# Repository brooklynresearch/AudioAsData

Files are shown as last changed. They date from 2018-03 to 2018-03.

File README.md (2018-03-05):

Vibrotextiles
=============
This repo is for all hardware and firmware associated with the vibrotextiles.
This is still a work in progress and will be updated as future commits occur.

Firmware
--------
This folder contains all the firmware, libraries, and testing instructions for the vibrotextiles

Javascript
----------
This folder contains a simple web based tester for APSK.

Hardware
--------
This folder contains all the schematics, layouts, components, production files, and artwork needed for the vibrotextiles.

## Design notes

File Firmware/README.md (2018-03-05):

Vibrotextiles - Firmware
========================
This Folder is for all the firmware and test processes associated with the vibrotextiles

Arduino
--------
This folder contains all the initial arduino code and possible libraries for the [NRF53832 BLE module](https://www.adafruit.com/product/3406).
Follow this [Adafruit NRF52832 Tutorial](https://learn.adafruit.com/bluefruit-nrf52-feather-learning-guide/introduction) to get started.

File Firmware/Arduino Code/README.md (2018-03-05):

Vibrotextiles - Arduino Code
============================
 To get started uploading code to the NRF52832 module sue the [Adafruit NRF52832 Tutorial](https://learn.adafruit.com/bluefruit-nrf52-feather-learning-guide/introduction).

 openocd
 -------
 Setup for debugging.  

 sketch_ppi_test
 ---------------
 Current working sketch

 sketch_testADC
 --------------
 Testing the ADC on the NRF52832

 test_code
 ---------
 Initial test code

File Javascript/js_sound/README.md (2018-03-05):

Vibrotextiles - js_sound
========================
This folder is for quick testing of the APSK function with the initial tests BKR did for the NRF52832

index
--------
Original javascript app to send data through APSK moduation.  Does not contain any error correction/checksum.

onthefly
----------
This folder contains a simple web based tester for APSK  Each data frame has 5 bytes, 4 of them are data, 1 of them is CRC checksum. At 1200 bps.  The carrier frequency is 1.2kHz to 2.2kHz.

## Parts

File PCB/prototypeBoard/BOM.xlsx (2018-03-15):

Qty | Value | Device | Package | Parts | Description | DIGIKEY | LCSC | PROD_ID | SF_ID | SPICEPREFIX | VALUE | 10 sets count
4 | 100 | RESISTOR0805_NOOUTLINE | 0805-NO | R18, R19, R31, R32 | Resistors |  | C153166 |  |  |  |  | 40
6 | 100k | R-EU_R0805 | R0805 | R5, R8, R9, R11, R12, R17 | RESISTOR, European symbol |  | C103905 |  |  | R |  | 60
4 | 100nF | C-EUC0805 | C0805 | C13, C17, C18, C29 | CAPACITOR, European symbol |  | C28378 |  |  | C |  | 40
4 | 10k | R-EU_R0805 | R0805 | R7, R20, R24, R28 | RESISTOR, European symbol |  | C84376 |  |  | R |  | 40
11 | 10uF | C-EUC0805 | C0805 | C3, C5, C6, C8, C10, C11, C14, C15, C16, C21, C25 | CAPACITOR, European symbol |  | C1713 |  |  | C |  | 110
2 | 10uH | INDUCTOR0805-NO | 0805-NO@1 | L1, L2 | Inductors |  | C112611 |  |  |  |  | 20
1 | 1N4148 | DIODESOD-323 | SOD-323 | D4 | Diode |  | C99332 |  |  |  |  | 10
7 | 1k | R-EU_R0805 | R0805 | R1, R2, R3, R13, R16, R29, R30 | RESISTOR, European symbol |  | C101404 |  |  | R |  | 70
1 | 1nF | C-EUC0805 | C0805 | C12 | CAPACITOR, European symbol |  | C16005 |  |  | C |  | 10
5 | 1uF | C-EUC0805 | C0805 | C4, C19, C20, C24, C26 | CAPACITOR, European symbol |  | C29822 |  |  | C |  | 50
1 | 2.2K | R-EU_R0805 | R0805 | R10 | RESISTOR, European symbol |  | C101970 |  |  | R |  | 10
2 | 20k | R-EU_R0805 | R0805 | R14, R15 | RESISTOR, European symbol |  | C101548 |  |  | R |  | 20
4 | 220pF | CAP_CERAMIC0805-NOOUTLINE | 0805-NO | C22, C23, C35, C36 | Ceramic Capacitors |  | C46326 |  |  |  |  | 40
2 | 22pF | C-EUC0805 | C0805 | C1, C2 | CAPACITOR, European symbol |  | C1836 |  |  | C |  | 20
1 | 2M | R-EU_R0805 | R0805 | R6 | RESISTOR, European symbol |  | C26112 |  |  | R |  | 10
2 | 300pF | C-EUC0805 | C0805 | C7, C9 | CAPACITOR, European symbol |  | C1735 |  |  | C |  | 20
1 | 32.768 | XTAL-3.2X1.5 | XTAL3215 | X4 | Low cost SMT crystals, no capacitors included |  | C48615 |  |  |  |  | 10
1 | 4u20329 | USB_MICRO_20329_V2 | 4UCONN_20329_V2 | X3 | USB Connectors |  | C91146 |  |  |  |  | 10
4 | 5K | R-EU_R0805 | R0805 | R21, R22, R34, R35 | RESISTOR, European symbol |  | C84375 |  |  | R |  | 40
1 | 806K | R-EU_R0805 | R0805 | R4 | RESISTOR, European symbol |  | C104516 |  |  | R |  | 10
2 | AP2112(3.3V) | VREG_SOT23-5 | SOT23-5 | U2, U5 | SOT23-5 Fixed Voltage Regulators |  | C51118 |  |  |  |  | 20
2 | APA1022020 | APA1022020 | APA102_2020 | U$45, U$51 | APA102C 5050 RGB LED | 1568-1826-ND |  |  |  |  |  | 20
1 | BLUE | LED0805_NOOUTLINE | CHIPLED_0805_NOOUTLINE | D2 | LED |  | C2293 |  |  |  |  | 10
1 | DFU | SWITCH_TACT_SMT4.6X2.8 | BTN_KMR2_4.6X2.8 | SW2 | SMT Tact Switches | CKN10246CT-ND |  |  |  |  |  | 10
1 | DMG3415U-7 | MOSFET-P | SOT23-R | Q3 | P-Channel Mosfet |  | C10487 |  |  |  |  | 10
1 | FRST | TESTPOINT1.5X2.0MM_NOCREAM | PAD-1.5X2.0 | TP2 | Test Point |  |  |  |  |  |  | 10
4 | Ferrite | FERRITE_0805 | _0805 | FB1, FB2, FB5, FB6 | Ferrite Bead |  | C12389 |  |  |  |  | 40
1 | JSTPH | CON_JST_PH_2PIN | JSTPH2 | X2 | JST 2-Pin Right-Angle Connector | 455-1749-1-ND |  |  |  |  |  | 10
1 | LMV324 | LMV324 | SO14 | U4 | IC LMV324 Quad Op Amp |  | C7974 | IC-08227 |  |  | LMV324 | 10
1 | MBR120 | DIODE-SCHOTTKYSOD-123 | SOD-123 | D5 |  |  | C130880 |  |  |  |  | 10
1 | MCP73831T-2ACI/OT | MCP73831/2 | SOT23-5 | U3 | MCP73831/2 LIPO Charger |  | C14879 |  |  |  |  | 10
1 | MDBT42 | NRF52832_MODULE_MDBT42 | BLE_MODULE_RAYTAC_MDBT42 | U1 | MDBT42 - BLE Module (nRF52832 QFN) | 1597-1434-ND |  |  |  |  |  | 10
1 | ORANGE | LED0805_NOOUTLINE | CHIPLED_0805_NOOUTLINE | CHG | LED |  | C154481 |  |  |  |  | 10
2 | PAM8302AASCR | AUDIOAMP_PAM8302A | MSOP8_0.65MM | U6, U8 | PAM8302A - 2.5W Class-D Mono Audio Amplifier |  | C113367 |  |  |  |  | 20
1 | RED | LED0805_NOOUTLINE | CHIPLED_0805_NOOUTLINE | D1 | LED |  | C72037 |  |  |  |  | 10
1 | RST | SWITCH_TACT_SMT4.6X2.8 | BTN_KMR2_4.6X2.8 | SW1 | SMT Tact Switches | CKN10246CT-ND |  |  |  |  |  | 10
1 | SWITCH_SPDT | SWITCH_SPDT | KPS-1290 | SW3 | SWCH-10651 |  | C128955 | SWCH-10651 |  |  |  | 10
2 | TBD | CAP_CERAMIC0805-NOOUTLINE | 0805-NO | C30, C37 | Ceramic Capacitors |  |  |  |  |  |  | 20

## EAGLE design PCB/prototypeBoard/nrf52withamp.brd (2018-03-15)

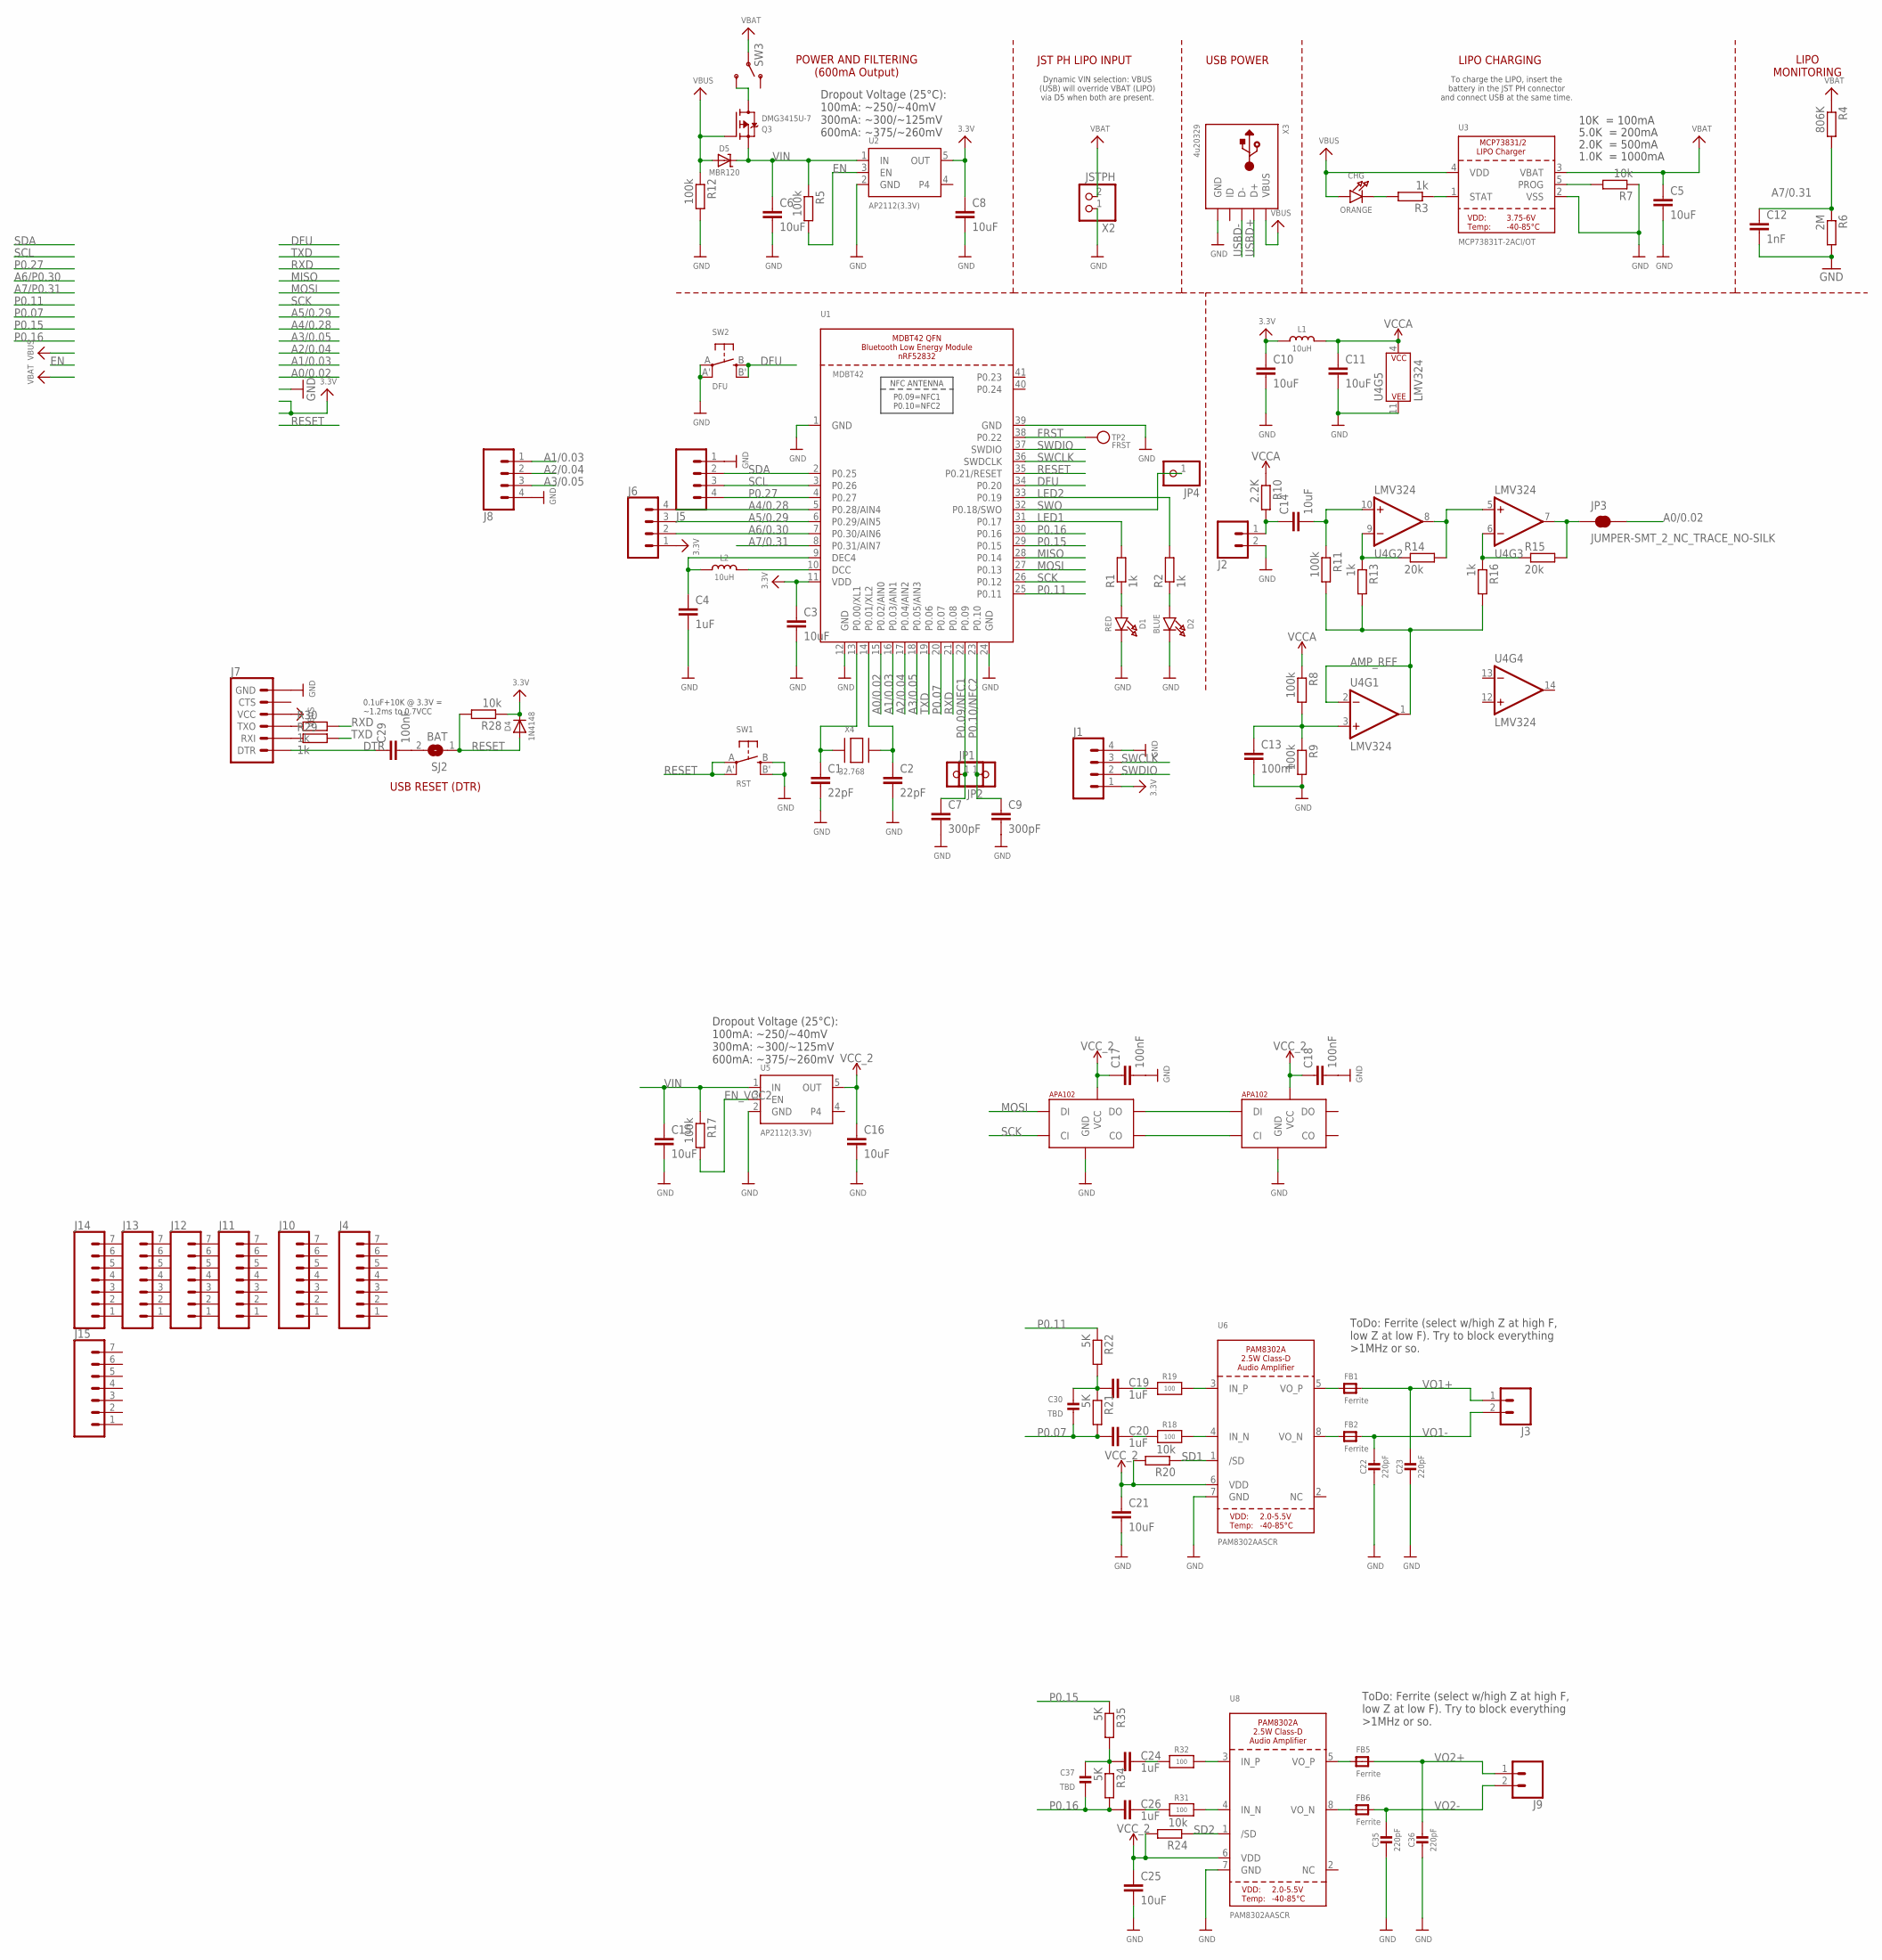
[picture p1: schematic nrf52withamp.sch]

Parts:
C1, C2: 22pF; C0805; LCSC C1836
C3, C5, C6, C8, C10, C11, C14, C15, C16, C21, C25: 10uF; C0805; LCSC C1713
C4, C19, C20, C24, C26: 1uF; C0805; LCSC C29822
C7, C9: 300pF; C0805; LCSC C1735
C12: 1nF; C0805; LCSC C16005
C13, C17, C18, C29: 100nF; C0805; LCSC C28378
C22, C23, C35, C36: 220pF; 0805-NO; LCSC C46326
C30, C37: TBD; 0805-NO
CHG: ORANGE; CHIPLED_0805_NOOUTLINE; LCSC C154481
D1: RED; CHIPLED_0805_NOOUTLINE; LCSC C72037
D2: BLUE; CHIPLED_0805_NOOUTLINE; LCSC C2293
D4: 1N4148; SOD-323; LCSC C99332
D5: MBR120; SOD-123; LCSC C130880
FB1, FB2, FB5, FB6: Ferrite; _0805; LCSC C12389
J1: CONN_04SMD; 1X04_SMD_RA_MALE
J2, J3, J9: CONN_02; 1X02
J4, J10, J11, J12, J13, J14, J15: CONN_07; 1X07
J5, J6, J8: CONN_041.27MM; 1X04_1.27MM
J7: 6_PIN_SERIAL_TARGETRA_SMT; 6_PIN_SERIAL_TARGET_SIDE_RA_SMT
JP1, JP2, JP4: HEADER-1X12MM; 1X01_2MM
JP3: JUMPER-SMT_2_NC_TRACE_NO-SILK; SMT-JUMPER_2_NC_TRACE_NO-SILK
L1, L2: 10uH; 0805-NO@1; LCSC C112611
Q3: DMG3415U-7; SOT23-R; LCSC C10487
R1, R2, R3, R13, R16, R29, R30: 1k; R0805; LCSC C101404
R4: 806K; R0805; LCSC C104516
R5, R8, R9, R11, R12, R17: 100k; R0805; LCSC C103905
R6: 2M; R0805; LCSC C26112
R7, R20, R24, R28: 10k; R0805; LCSC C84376
R10: 2.2K; R0805; LCSC C101970
R14, R15: 20k; R0805; LCSC C101548
R18, R19, R31, R32: 100; 0805-NO; LCSC C153166
R21, R22, R34, R35: 5K; R0805; LCSC C84375
SJ2: BAT; SOLDERJUMPER_CLOSEDWIRE
SW1: RST; BTN_KMR2_4.6X2.8; DIGIKEY CKN10246CT-ND
SW2: DFU; BTN_KMR2_4.6X2.8; DIGIKEY CKN10246CT-ND
SW3: SWITCH_SPDT; KPS-1290; LCSC C128955
TP2: FRST; PAD-1.5X2.0
U1: MDBT42; BLE_MODULE_RAYTAC_MDBT42; DIGIKEY 1597-1434-ND
U2, U5: AP2112(3.3V); SOT23-5; LCSC C51118
U3: MCP73831T-2ACI/OT; SOT23-5; LCSC C14879
U4: LMV324; SO14; LCSC C7974
U6, U8: PAM8302AASCR; MSOP8_0.65MM; LCSC C113367
U$45, U$51: APA1022020; APA102_2020; DIGIKEY 1568-1826-ND
X2: JSTPH; JSTPH2; DIGIKEY 455-1749-1-ND
X3: 4u20329; 4UCONN_20329_V2; LCSC C91146
X4: 32.768; XTAL3215; LCSC C48615

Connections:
3.3V: C3.1, C8.1, C10.1, D4.C, J1.1, J6.1, L1.1, R28.1, U1.11 (VDD), U2.5 (OUT)
A0/0.02: JP3.2, U1.15 (P0.02/AIN0)
A1/0.03: J8.1, U1.16 (P0.03/AIN1)
A2/0.04: J8.2, U1.17 (P0.04/AIN2)
A3/0.05: J8.3, U1.18 (P0.05/AIN3)
A4/0.28: J6.4, U1.5 (P0.28/AIN4)
A5/0.29: J6.3, U1.6 (P0.29/AIN5)
A6/0.30: J6.2, U1.7 (P0.30/AIN6)
A7/0.31: C12.1, R4.2, R6.1, U1.8 (P0.31/AIN7)
AMP_REF: R11.2, R13.2, R16.2, U4.1 (OUT), U4.2 (-IN)
CO1: U$45.CL_OUT (CO), U$51.C_IN (CI)
DFU: SW2.B (S), SW2.B' (S1), U1.34 (P0.20)
DTR: C29.1, J7.1 (DTR)
EN: R5.2, U2.3 (EN)
EN_VCC2: R17.2, U5.3 (EN)
FRST: TP2.P$1, U1.38 (P0.22)
GND: C1.2, C2.2, C3.2, C4.2, C5.2, C6.2, C7.2, C8.2, C9.2, C10.2, C11.2, C12.2, C13.2, C15.2, C16.2, C17.2, C18.2, C21.2, C22.2, C23.2, C25.2, C35.2, C36.2, D1.C, D2.C, J1.4, J2.2, J5.1, J7.6 (GND), J8.4, R6.2, R7.1, R9.2, R12.2, SW1.B (S), SW1.B' (S1), SW2.A, SW2.A' (P1), U1.1 (GND), U1.12 (GND), U1.24 (GND), U1.39 (GND), U2.2 (GND), U3.2 (VSS), U4.11 (P$V-), U5.2 (GND), U6.7 (GND), U8.7 (GND), U$45.GND, U$51.GND, X2.1, X3.BASE@1 (GND), X3.BASE@2 (GND), X3.GND, X3.SPRT@1 (GND), X3.SPRT@2 (GND), X3.SPRT@3 (GND), X3.SPRT@4 (GND)
LED1: R1.2, U1.31 (P0.17)
LED2: R2.2, U1.33 (P0.19)
MISO: U1.28 (P0.14)
MOSI: U1.27 (P0.13), U$45.D_IN (DI)
unnamed: C1.1, U1.13 (P0.00/XL1), X4.P$1
unnamed: C2.1, U1.14 (P0.01/XL2), X4.P$2
unnamed: L2.2, U1.10 (DCC)
unnamed: CHG.C, R3.2
unnamed: D1.A, R1.1
unnamed: C13.1, R8.2, R9.1, U4.3 (+IN)
unnamed: D2.A, R2.1
unnamed: C4.1, L2.1, U1.9 (DEC4)
unnamed: R3.1, U3.1 (STAT)
unnamed: R7.2, U3.5 (PROG)
unnamed: C14.1, J2.1, R10.2
unnamed: C14.2, R11.1, U4.10 (+IN)
unnamed: C29.2, SJ2.2
unnamed: U$45.D_OUT (DO), U$51.D_IN (DI)
unnamed: R13.1, R14.1, U4.9 (-IN)
unnamed: R14.2, U4.5 (+IN), U4.8 (OUT)
unnamed: R15.1, R16.1, U4.6 (-IN)
unnamed: JP3.1, R15.2, U4.7 (OUT)
unnamed: R18.2, U6.4 (IN_N)
unnamed: R19.2, U6.3 (IN_P)
unnamed: C20.2, R18.1
unnamed: FB2.1, U6.8 (VO_N)
unnamed: FB1.1, U6.5 (VO_P)
unnamed: C19.2, R19.1
unnamed: C19.1, C30.1, R21.1, R22.2
unnamed: Q3.3 (D), SW3.S
unnamed: J7.3 (RXI), R29.1
unnamed: J7.2 (TXO), R30.1
unnamed: R31.2, U8.4 (IN_N)
unnamed: R32.2, U8.3 (IN_P)
unnamed: C26.2, R31.1
unnamed: FB6.1, U8.8 (VO_N)
unnamed: FB5.1, U8.5 (VO_P)
unnamed: C24.2, R32.1
unnamed: C24.1, C37.1, R34.1, R35.2
P0.07: C20.1, C30.2, R21.2, U1.20 (P0.07)
P0.09/NFC1: C7.1, JP2.1, U1.22 (P0.09)
P0.10/NFC2: C9.1, JP1.1, U1.23 (P0.10)
P0.11: R22.1, U1.25 (P0.11)
P0.15: R35.1, U1.29 (P0.15)
P0.16: C26.1, C37.2, R34.2, U1.30 (P0.16)
P0.27: J5.4, U1.4 (P0.27)
RESET: D4.A, R28.2, SJ2.1, SW1.A, SW1.A' (P1), U1.35 (P0.21/RESET)
RXD: R30.2, U1.21 (P0.08)
SCK: U1.26 (P0.12), U$45.C_IN (CI)
SCL: J5.3, U1.3 (P0.26)
SD1: R20.1, U6.1 (/SD)
SD2: R24.1, U8.1 (/SD)
SDA: J5.2, U1.2 (P0.25)
SWCLK: J1.3, U1.36 (SWDCLK)
SWDIO: J1.2, U1.37 (SWDIO)
SWO: JP4.1, U1.32 (P0.18/SWO)
TXD: R29.2, U1.19 (P0.06)
USBD+: X3.D+
USBD-: X3.D-
VBAT: C5.1, R4.1, SW3.P, U3.3 (VBAT), X2.2
VBUS: CHG.A, D5.A, J7.4 (VCC), Q3.1 (G), R12.1, U3.4 (VDD), X3.VBUS
VCCA: C11.1, L1.2, R8.1, R10.1, U4.4 (P$V+)
VCC_2: C16.1, C17.1, C18.1, C21.1, C25.1, R20.2, R24.2, U5.5 (OUT), U6.6 (VDD), U8.6 (VDD), U$45.V_CC (VCC), U$51.V_CC (VCC)
VIN: C6.1, C15.1, D5.C, Q3.2 (S), R5.1, R17.1, U2.1 (IN), U5.1 (IN)
VO1+: C23.1, FB1.2, J3.1
VO1-: C22.1, FB2.2, J3.2
VO2+: C36.1, FB5.2, J9.1
VO2-: C35.1, FB6.2, J9.2

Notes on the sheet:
10K = 100mA
5.0K = 200mA
2.0K = 500mA
1.0K = 1000mA
LIPO CHARGING
LIPO MONITORING
To charge the LIPO, insert the battery in the JST PH connector and connect USB at the same time.
POWER AND FILTERING (600mA Output)
JST PH LIPO INPUT
Dynamic VIN selection: VBUS (USB) will override VBAT (LIPO) via D5 when both are present.
Dropout Voltage (25°C): 100mA: ~250/~40mV 300mA: ~300/~125mV 600mA: ~375/~260mV
USB POWER
ToDo: Ferrite (select w/high Z at high F, low Z at low F). Try to block everything >1MHz or so.
USB RESET (DTR)
0.1uF+10K @ 3.3V = ~1.2ms to 0.7VCC

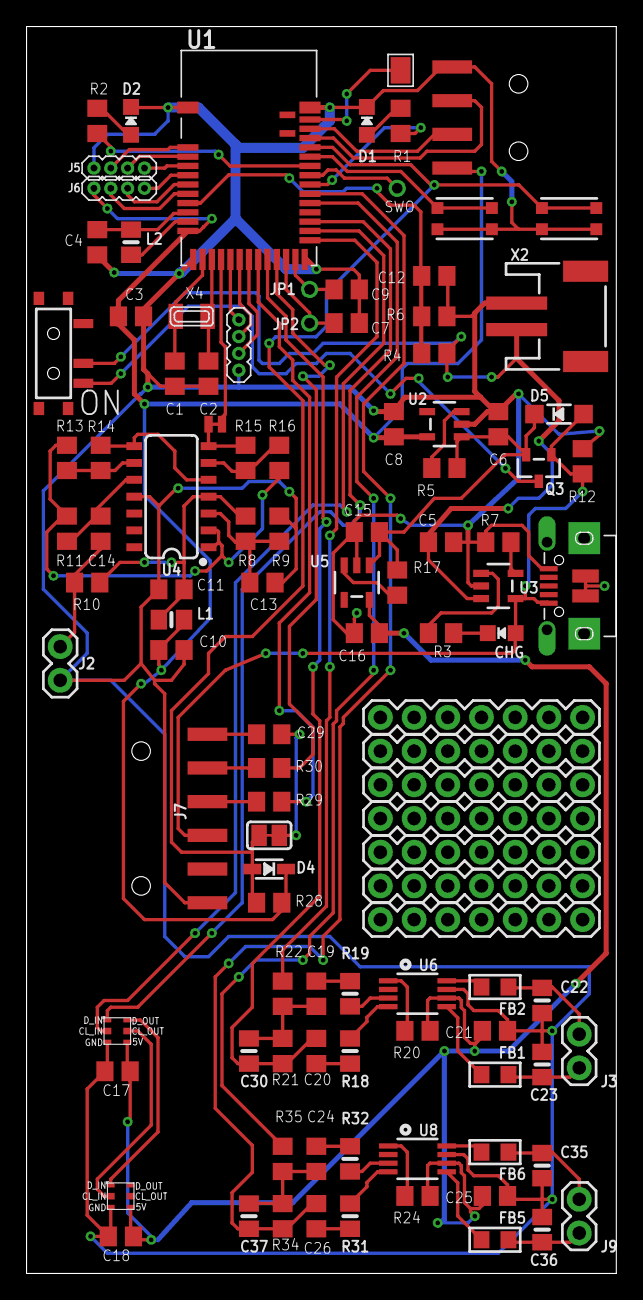
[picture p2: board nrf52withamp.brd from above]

Board: 2 copper layers, 44.5 x 94.0 mm, 109 parts (0 on the bottom side), 82 nets.

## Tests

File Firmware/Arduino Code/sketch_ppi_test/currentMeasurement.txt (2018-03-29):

Measured on Mar 29 2018. With nrf52withamp.brd, Lofelt actuator, OTOjOY induction loop sensor.

Current measured on VBus with Fluke 15B 

LED off, Motor off: 19.25 mA
1 LED Full brightness, Motor off: 34.65mA
2 LED Full brightness, Motor off: 55.2mA
LED off, Motor full vibration @ 100hz: 317 mA
LED off, Motor full vibration @ 10hz: 351 mA
2 LED Full brightness, Motor full vibration @ 100hz: 351mA
2 LED Full brightness, Motor full vibration @ 10hz: 388mA

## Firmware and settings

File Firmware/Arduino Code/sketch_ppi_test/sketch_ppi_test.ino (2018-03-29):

//tested with Univox AutoLoop 2.0 Home Hearing Loop System, modulated with bell202

#define SIGNAL_LEVEL_PIN A6
#define DEBUG_PIN1 A5
#define DEBUG_PIN2 A4
#define NRF52_BLUE_LED 19

#define BUZZER1_PIN1 11
#define BUZZER1_PIN2 7

#define BUZZER2_PIN1 15
#define BUZZER2_PIN2 16

#include <SPI.h>

extern "C"  //https://forums.adafruit.com/viewtopic.php?f=24&t=125410
{
  void TIMER1_IRQHandler();
  void SAADC_IRQHandler();
}

volatile int16_t adcbuffer; //interrupt one each time. other wise auto restart has aline issue

volatile int16_t historyBuffer[8];

volatile bool newData = false;

bool recent3bits[3];

int recent3Bytes[3];

bool outputBit;

int capturePhase = 0;
int processingValue;

unsigned char CRCtable[256] = {0x00, 0x07, 0x0e, 0x09, 0x1c, 0x1b, 0x12, 0x15, 0x38, 0x3f, 0x36, 0x31, 0x24, 0x23, 0x2a, 0x2d, 0x70, 0x77, 0x7e, 0x79, 0x6c, 0x6b, 0x62, 0x65, 0x48, 0x4f, 0x46, 0x41, 0x54, 0x53, 0x5a, 0x5d, 0xe0, 0xe7, 0xee, 0xe9, 0xfc, 0xfb, 0xf2, 0xf5, 0xd8, 0xdf, 0xd6, 0xd1, 0xc4, 0xc3, 0xca, 0xcd, 0x90, 0x97, 0x9e, 0x99, 0x8c, 0x8b, 0x82, 0x85, 0xa8, 0xaf, 0xa6, 0xa1, 0xb4, 0xb3, 0xba, 0xbd, 0xc7, 0xc0, 0xc9, 0xce, 0xdb, 0xdc, 0xd5, 0xd2, 0xff, 0xf8, 0xf1, 0xf6, 0xe3, 0xe4, 0xed, 0xea, 0xb7, 0xb0, 0xb9, 0xbe, 0xab, 0xac, 0xa5, 0xa2, 0x8f, 0x88, 0x81, 0x86, 0x93, 0x94, 0x9d, 0x9a, 0x27, 0x20, 0x29, 0x2e, 0x3b, 0x3c, 0x35, 0x32, 0x1f, 0x18, 0x11, 0x16, 0x03, 0x04, 0x0d, 0x0a, 0x57, 0x50, 0x59, 0x5e, 0x4b, 0x4c, 0x45, 0x42, 0x6f, 0x68, 0x61, 0x66, 0x73, 0x74, 0x7d, 0x7a, 0x89, 0x8e, 0x87, 0x80, 0x95, 0x92, 0x9b, 0x9c, 0xb1, 0xb6, 0xbf, 0xb8, 0xad, 0xaa, 0xa3, 0xa4, 0xf9, 0xfe, 0xf7, 0xf0, 0xe5, 0xe2, 0xeb, 0xec, 0xc1, 0xc6, 0xcf, 0xc8, 0xdd, 0xda, 0xd3, 0xd4, 0x69, 0x6e, 0x67, 0x60, 0x75, 0x72, 0x7b, 0x7c, 0x51, 0x56, 0x5f, 0x58, 0x4d, 0x4a, 0x43, 0x44, 0x19, 0x1e, 0x17, 0x10, 0x05, 0x02, 0x0b, 0x0c, 0x21, 0x26, 0x2f, 0x28, 0x3d, 0x3a, 0x33, 0x34, 0x4e, 0x49, 0x40, 0x47, 0x52, 0x55, 0x5c, 0x5b, 0x76, 0x71, 0x78, 0x7f, 0x6a, 0x6d, 0x64, 0x63, 0x3e, 0x39, 0x30, 0x37, 0x22, 0x25, 0x2c, 0x2b, 0x06, 0x01, 0x08, 0x0f, 0x1a, 0x1d, 0x14, 0x13, 0xae, 0xa9, 0xa0, 0xa7, 0xb2, 0xb5, 0xbc, 0xbb, 0x96, 0x91, 0x98, 0x9f, 0x8a, 0x8d, 0x84, 0x83, 0xde, 0xd9, 0xd0, 0xd7, 0xc2, 0xc5, 0xcc, 0xcb, 0xe6, 0xe1, 0xe8, 0xef, 0xfa, 0xfd, 0xf4, 0xf3};


void setup() {

  NRF_CLOCK->TASKS_HFCLKSTART = 1; while (!NRF_CLOCK->EVENTS_HFCLKSTARTED) {} //increase accuracy

  pinMode(LED_BUILTIN, OUTPUT);
  pinMode(NRF52_BLUE_LED, OUTPUT);

  analogWrite(NRF52_BLUE_LED, 128); //set up PWM, This should be on channel 0 of HwPWM0
  analogWrite(LED_BUILTIN, 128); //channel 1 of HwPWM0

  pinMode(7, OUTPUT);
  pinMode(SIGNAL_LEVEL_PIN, OUTPUT);
  pinMode(DEBUG_PIN1, OUTPUT);
  pinMode(DEBUG_PIN2, OUTPUT);

  pinMode(BUZZER1_PIN1, OUTPUT);
  pinMode(BUZZER1_PIN2, OUTPUT);

  pinMode(BUZZER2_PIN1, OUTPUT);
  pinMode(BUZZER2_PIN2, OUTPUT);

  Serial.begin(115200);

  //set up PWM
  HwPWM2.begin();
  NRF_PWM2->MODE = (PWM_MODE_UPDOWN_UpAndDown << PWM_MODE_UPDOWN_Pos);

  HwPWM2.setClockDiv(PWM_PRESCALER_PRESCALER_DIV_64);

  HwPWM2.addPin(BUZZER1_PIN1);  //add motorPWM to PWM2
  HwPWM2.addPin(BUZZER1_PIN2);  //add motorPWM to PWM2

  HwPWM2.addPin(BUZZER2_PIN1);  //add motorPWM to PWM2
  HwPWM2.addPin(BUZZER2_PIN2);  //add motorPWM to PWM2

  HwPWM2.setMaxValue(1250); //freq: 16E6/64/1250/2
  HwPWM2.writeChannel(0, 1, false);
  HwPWM2.writeChannel(1, 1250 - 1, true);
  HwPWM2.writeChannel(2, 1, false);
  HwPWM2.writeChannel(3, 1250 - 1, true);

  ppi_init();
  timer1_init(); // Timer used to increase m_counter every 100ms.
  saadc_init();
  saadc_read();// Trigger first SAADC read

  SPI.begin();
  SPI.setClockDivider((F_CPU + 4000000L) / 2000000L); // 2-ish MHz on Due
  SPI.setBitOrder(MSBFIRST);
  SPI.setDataMode(SPI_MODE0);

  
  analogWrite(NRF52_BLUE_LED, 0); //set up PWM, This should be on channel 0 of HwPWM0
  analogWrite(LED_BUILTIN, 0); //channel 1 of HwPWM0

}



void loop() {
  bool ledUpdate = false;
  int led1Value, led2Value;

  if (newData) {
    int32_t demodulateValue = demodulate8Byte((int16_t *)historyBuffer);

#define THRES_MAX   1000L
#define THRES_MIN  -1000L

    if (outputBit == 0) {
      if (demodulateValue > THRES_MAX) outputBit = 1;
    } else {
      if (demodulateValue < THRES_MIN) outputBit = 0;
    }

    unsigned char dataBuffer;
    unsigned char clock_regen_result = clock_regen(outputBit, &dataBuffer);
    static unsigned char receivedData[5];
    static int receivedLength = 0;
    if (clock_regen_result == 1) {
      for (int i = 0; i < 4; i++) {
        receivedData[i] = receivedData[i + 1];
      }
      receivedData[4] = dataBuffer;
      receivedLength++;
      if (receivedLength >= 5) {
        unsigned char crcValue = 0;
        for (int i = 0; i < 4; i++) {
          crcValue = CRCtable[ (crcValue ^ receivedData[i]) ];
        }
        if (receivedData[4] == crcValue) {
          //Serial.println(dataBuffer,HEX);
          ledUpdate = true;
          led1Value = receivedData[0];
          led2Value = receivedData[1];

          //set Motor
          int pwmMaxValue = 125000 / receivedData[2];
          HwPWM2.setMaxValue(pwmMaxValue); //freq: 16E6/64/1250/2
          int pwmValue = pwmMaxValue * receivedData[3] >> 9;
          HwPWM2.writeChannel(0, pwmValue, false);
          HwPWM2.writeChannel(1, pwmMaxValue - pwmValue, true);
          HwPWM2.writeChannel(2, pwmValue, false);
          HwPWM2.writeChannel(3, pwmMaxValue - pwmValue, true);

          receivedLength = 0;
          memset(receivedData, 0, 5);
        }
      }
    } else if (clock_regen_result == 2) {
      //10 bit reset
      receivedLength = 0;
    }

    digitalWrite(SIGNAL_LEVEL_PIN, outputBit);

    newData = false;
  }

  if (ledUpdate) {
    sendLEDValue(led1Value, led1Value, led1Value, led2Value, led2Value, led2Value);
  }
}

#define PHASE_INC 256/8 // 2^(length of phase register)/samples per bit
#define PHASE_CORR PHASE_INC/2

unsigned char clock_regen(uint8_t r, uint8_t *result) {
  unsigned char returnVal = 0;
  static uint8_t bit_phase;
  static uint8_t oldr;
  static uint8_t oldoldr;
  uint16_t temp;
  if (oldr != r) { //edge detection
    if (bit_phase < 0x80) {
      bit_phase += PHASE_CORR;
    } else {
      bit_phase -= PHASE_CORR;
    }
  }
  temp = bit_phase + PHASE_INC;
  bit_phase = temp & 0xff;
  if (temp > 0xff) { //sample at half cycle
    //sample 2 in 3

    uint8_t TMRdecode = ((r + oldr + oldoldr) >= 2) ? 1 : 0;

    //
    static int idleBitCount = 1;
    static int sampleBitCount = 0;
    static unsigned char dataBuffer = 0;

    if (idleBitCount > 0) {
      if (!TMRdecode) { //start bit
        sampleBitCount = 0;
        idleBitCount = 0;
      } else {
        idleBitCount++;
        if (idleBitCount >= 10) {
          idleBitCount = 10;
          returnVal = 2;
          dataBuffer = 0;
        }
      }
    } else {
      dataBuffer = dataBuffer >> 1;
      if (TMRdecode) dataBuffer |= 0x80;
      sampleBitCount++;
      if (sampleBitCount == 8) {
        returnVal = 1;
        *result = dataBuffer;
      } else if (sampleBitCount == 9) {
        idleBitCount = 1;
      }

    }
  }
  oldoldr = oldr;
  oldr = r;

  return returnVal;
}


int16_t Coeffloi[] = {32767, 23169, 0, -23169, -32767, -23169, 0, 23169}; //1200 Hz tone for mark (typically a binary 1)
int16_t Coeffloq[] = {0, 23169, 32767, 23169, 0, -23169, -32767, -23169};
int16_t Coeffhii[] = {32767, 4276, -31650, -12539, 28377, 19947, -23169, //2200 Hz for space (typically a binary 0)
                      -25995
                     };
int16_t Coeffhiq[] = {0, 32486, 8480, -30272, -16383, 25995, 23169, -19947};

int32_t demodulate8Byte(int16_t *data) {
  int32_t outloi, outloq, outhii, outhiq;
  int16_t d;
  uint8_t i;

  outloi = 0;
  outloq = 0;
  outhii = 0;
  outhiq = 0;

  for (i = 0; i < 8; i++) {
    d = data[i];
    outloi += d * Coeffloi[i];
    outloq += d * Coeffloq[i];
    outhii += d * Coeffhii[i];
    outhiq += d * Coeffhiq[i];
  }

  return (outloi >> 16) * (outloi >> 16) + (outloq >> 16) * (outloq >> 16) - ((outhii >> 16) * (outhii >> 16) + (outhiq >> 16) * (outhiq >> 16));
}

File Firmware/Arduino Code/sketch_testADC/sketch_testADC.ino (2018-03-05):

#include <Arduino.h>

#define SAMPLES_IN_BUFFER 10


static int16_t m_buffer_pool[2][SAMPLES_IN_BUFFER];

volatile bool saadc_results_ready = false;
volatile uint8_t saadc_use_buffer = 0;

// the setup function runs once when you press reset or power the board
void setup() {
  // initialize digital pin LED_BUILTIN as an output.
  pinMode(LED_BUILTIN, OUTPUT);
  pinMode(7, OUTPUT);
  pinMode(11, OUTPUT);

  digitalWrite(7, HIGH);
  digitalWrite(11, HIGH);

  Serial.begin(115200);

  analogA0init();

  digitalWrite(7, HIGH);

}




// the loop function runs over and over again forever
void loop() {


  digitalWrite(LED_BUILTIN, HIGH);   // turn the LED on (HIGH is the voltage level)
  delay(100);                       // wait for a second
  digitalWrite(LED_BUILTIN, LOW);    // turn the LED off by making the voltage LOW
  delay(100);

  int adcvalue = analogReadRawA0();
  // Display the results
  Serial.println(adcvalue);


}

int16_t valueA0;

void analogA0init() {
  uint32_t pin = SAADC_CH_PSELP_PSELP_NC;
  uint32_t saadcResolution;
  uint32_t resolution;

  NRF_SAADC->RESOLUTION = SAADC_RESOLUTION_VAL_10bit;

  NRF_SAADC->ENABLE = (SAADC_ENABLE_ENABLE_Enabled << SAADC_ENABLE_ENABLE_Pos);
  for (int i = 0; i < 8; i++) {
    NRF_SAADC->CH[i].PSELN = SAADC_CH_PSELP_PSELP_NC;
    NRF_SAADC->CH[i].PSELP = SAADC_CH_PSELP_PSELP_NC;
  }
  NRF_SAADC->CH[0].CONFIG = ((SAADC_CH_CONFIG_RESP_Bypass     << SAADC_CH_CONFIG_RESP_Pos)   & SAADC_CH_CONFIG_RESP_Msk)
                            | ((SAADC_CH_CONFIG_RESP_Bypass   << SAADC_CH_CONFIG_RESN_Pos)   & SAADC_CH_CONFIG_RESN_Msk)
                            | ((SAADC_CH_CONFIG_GAIN_Gain1_6                     << SAADC_CH_CONFIG_GAIN_Pos)   & SAADC_CH_CONFIG_GAIN_Msk)
                            | ((SAADC_CH_CONFIG_REFSEL_Internal                << SAADC_CH_CONFIG_REFSEL_Pos) & SAADC_CH_CONFIG_REFSEL_Msk)
                            | ((SAADC_CH_CONFIG_TACQ_3us      << SAADC_CH_CONFIG_TACQ_Pos)   & SAADC_CH_CONFIG_TACQ_Msk)
                            | ((SAADC_CH_CONFIG_MODE_SE       << SAADC_CH_CONFIG_MODE_Pos)   & SAADC_CH_CONFIG_MODE_Msk)
                            | ((SAADC_CH_CONFIG_BURST_Disabled            << SAADC_CH_CONFIG_BURST_Pos)   & SAADC_CH_CONFIG_BURST_Msk);
  NRF_SAADC->CH[0].PSELN = SAADC_CH_PSELP_PSELP_AnalogInput0;
  NRF_SAADC->CH[0].PSELP = SAADC_CH_PSELP_PSELP_AnalogInput0;


  NRF_SAADC->RESULT.PTR = (uint32_t)&valueA0;
  NRF_SAADC->RESULT.MAXCNT = 1; // One sample

}


uint32_t analogReadRawA0(void) {


  
  NRF_SAADC->ENABLE = (SAADC_ENABLE_ENABLE_Enabled << SAADC_ENABLE_ENABLE_Pos);
 


  NRF_SAADC->TASKS_START = 0x01UL;

  while (!NRF_SAADC->EVENTS_STARTED);
  NRF_SAADC->EVENTS_STARTED = 0x00UL;

  NRF_SAADC->TASKS_SAMPLE = 0x01UL;

  while (!NRF_SAADC->EVENTS_END);
  NRF_SAADC->EVENTS_END = 0x00UL;

  NRF_SAADC->TASKS_STOP = 0x01UL;

  while (!NRF_SAADC->EVENTS_STOPPED);
  NRF_SAADC->EVENTS_STOPPED = 0x00UL;

  if (valueA0 < 0) {
    valueA0 = 0;
  }

  NRF_SAADC->ENABLE = (SAADC_ENABLE_ENABLE_Disabled << SAADC_ENABLE_ENABLE_Pos);

  return valueA0;
}

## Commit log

2018-03-05 Initial Commit
    Initial Commit for Vibrotextiles
    [jlink.cfg, stlink-v2-1.cfg, stlink-v2.cfg]
2018-03-08 add board
    [nrf52withamp.brd, nrf52withamp.sch]
2018-03-08 move files
    [nrf52withamp.brd, nrf52withamp.sch]
2018-03-08 update code
    [nrf52withamp.brd, nrf52withamp.sch]
2018-03-11 add PCB
    [nrf52withamp.brd, nrf52withamp.sch]
2018-03-15 update board
    [BOM.xlsx, nrf52withamp.brd, nrf52withamp.sch]
2018-03-15 add bom and gerber
    [BOM.xlsx]
2018-03-26 add fix
    [nrf52withamp.sch, stlink.cfg]
2018-03-29 change pins to PCB pins

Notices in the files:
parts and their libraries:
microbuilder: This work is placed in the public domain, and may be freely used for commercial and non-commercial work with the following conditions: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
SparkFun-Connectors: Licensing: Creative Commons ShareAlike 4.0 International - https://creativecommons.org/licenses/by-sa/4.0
